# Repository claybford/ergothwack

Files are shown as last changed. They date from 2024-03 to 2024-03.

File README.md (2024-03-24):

# The ergoTHWACK: a custom wireless mechanical split keyboard

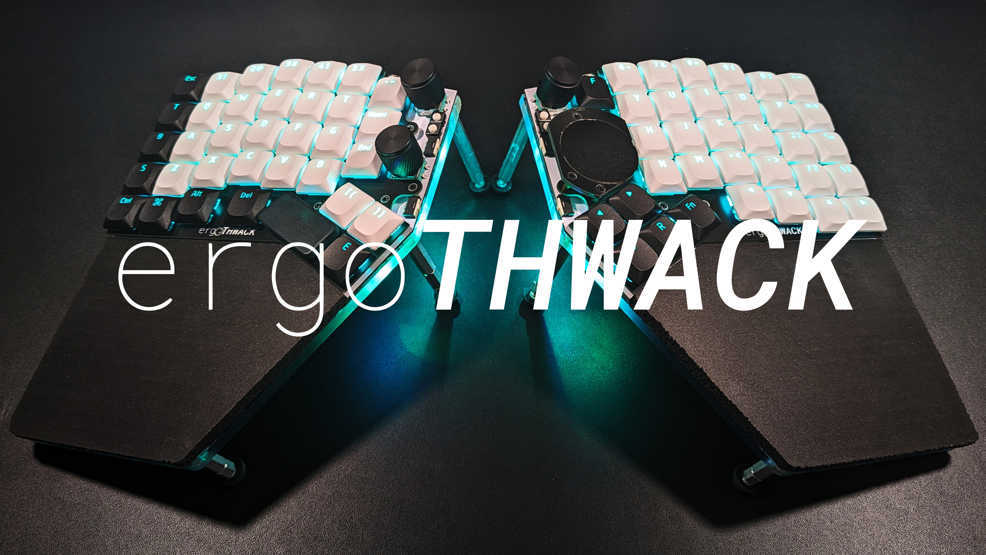
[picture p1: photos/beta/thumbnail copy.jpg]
picture alt headline photo with logo


This repository is for hardware development of the ergoTHWACK wireless mechanical split keyboard, designed by Clayton Ford.

The ergoTHWACK is a custom design, inspired by the ErgoDash by omkbd and the Corne GLP by beekeeb, that:
- requires no layer usage or memorization for general use
- has a 2U spacebar that is comfortably under the thumb for typing and gaming
- includes a Cirque Glidepoint 35mm trackpad and a rotary encoder for full mouse functionality without moving the right hand off the keyboard
- has an integrated wrist pad and tenting for ergonomics
- and uses Gateron KS-33 low-profile switches for more similarity in typing to non-mechanical keyboards.

In addition it has: 
- 2 more rotary encoders on the left
- RGB backlit keys and underglow
- tactile swiches for reset and settings control
- LED power shutoff switches
- and a 10000mAh battery on each side for plenty of wireless bluetooth backlit runtime.

For a quick overview of the design, check out the beta reveal trailer: https://www.youtube.com/watch?v=sj0JC6q0L3o

A longer write-up on the design rationale is here: https://www.claytonbford.com/portfolio/ergothwack

The ergoTHWACK uses the ZMK firmware and the nice!nano. For more information about each, please visit https://zmk.dev/ and https://nicekeyboards.com/nice-nano/ respectively.

Shield support for ZMK for the ergoTHWACK is here: https://github.com/claybford/ergothwack-shield-module

The ergoTHWACK uses a fork of ZMK to support all of its features, which its shield support repo uses and links to for building. It's directly available here: https://github.com/claybford/zmk

The ergoTHWACK keyboard is in beta, and there are several known issues with the design. Once a version is ready for others to try to build, a guide to do so will be made available!

Link to the ErgoDash by omkbd: https://github.com/omkbd/ErgoDash/tree/master

Link to the Corne GLP by beekeeb: https://github.com/beekeeb/crkbd-glp

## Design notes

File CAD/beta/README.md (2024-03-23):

Note: these CAD files are essentially the same, with the right side designed as a mirror image on the left (this is how the entire beta ergoTHWACK was designed). The only differences between these files are which bodies & components are visible on which.

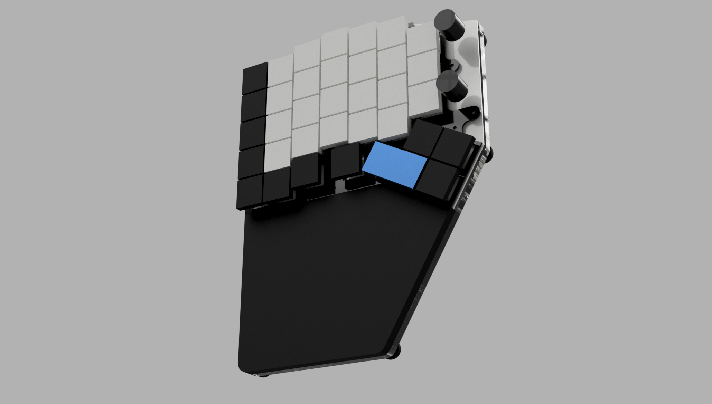
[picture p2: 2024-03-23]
renders/beta/ergothwack left.png

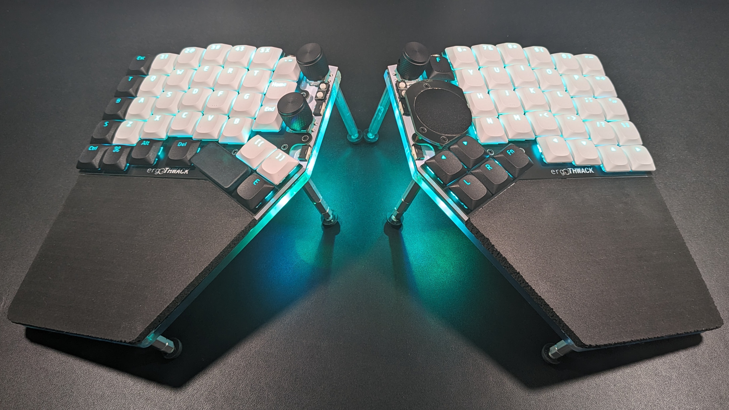
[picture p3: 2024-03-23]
photos/beta/PXL_20240321_203455422~2.jpg

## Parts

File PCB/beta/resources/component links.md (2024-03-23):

https://github.com/bstiq/nice-nano-kicad
https://github.com/madworm/Panelization.pretty
https://github.com/siderakb/key-switches.pretty
https://github.com/beekeeb/crkbd-glp

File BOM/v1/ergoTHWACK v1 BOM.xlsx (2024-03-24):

part | description | pack quantity | vendor | price | quantity | line total | subtotal | exact quantities used | notes | link | Note: exact quantities given in non-pack lines
86375K142 | Resilient Polyurethane Foam Sheet with Adhesive-Back, Ultra Soft, 12" x 12" x 1/4" |  | McMaster-Carr | 23.72 | 1 | 23.72 | $477.47 |  |  |  | retain from beta
93505A449 | Male-Female Threaded Hex Standoff Aluminum, 1/4" Hex Size, 2" Long, 6-32 Thread Size |  | McMaster-Carr | 1.34 | 2 | 2.68 | $611.49 |  |  |  | Removal from beta
93505A446 | Male-Female Threaded Hex Standoff Aluminum, 1/4" Hex Size, 1" Long, 6-32 Thread Size |  | McMaster-Carr | 0.72 | 2 | 1.44 | -$134.02 |  |  |  | targeted for change from beta
93505A442 | Male-Female Threaded Hex Standoff Aluminum, 1/4" Hex Size, 1/2" Long, 6-32 Thread Size |  | McMaster-Carr | 0.66 | 6 | 3.96 |  |  |  |  | Quantity change from beta
93505A440 | Male-Female Threaded Hex Standoff Aluminum, 1/4" Hex Size, 1/4" Long, 6-32 Thread Size |  | McMaster-Carr | 0.59 | 6 | 3.54 |  |  |  |  | v1 addition
9541K8 | Threaded-Stud Bumper SBR, 6-32 Thread, 7/16" OD, 1/4" High, Durometer 60A | 25 | McMaster-Carr | 10.84 | 1 | 10.84 |  | v1 8, beta 10 |  |  | custom component
97164A117 | Aluminum Tapered Heat-Set Inserts for Plastic M3 x 0.5 mm Thread Size, 3.81 mm Installed Length | 25 | McMaster-Carr | 8.82 | 0 | 0 |  |  | Eliminated by tapped steel baseplate |  | estimate
97164A110 | Aluminum Tapered Heat-Set Inserts for Plastic 6-32, 0.150" Installed Length | 25 | McMaster-Carr | 6.52 | 0 | 0 |  |  | Eliminated by tapped steel baseplate
94459A418 | Heat-Set Inserts for Plastic Aluminum, M2 x 0.4 mm, 4.1 mm Installed Length | 25 | McMaster-Carr | 7.75 | 0 | 0 |  |  | Eliminated by tapped steel baseplate
93935A305 | Super-Corrosion-Resistant 316 Stainless Steel Thin Hex Nut M2 x 0.4 mm Thread, 1.2 mm High | 25 | McMaster-Carr | 3.67 | 0 | 0 |  | 8 in beta | Eliminated by reversing screws
575-3154311241003000 | IC & Component Sockets Interconnect Socket 12 position |  | Mouser | 1.79 | 0 | 0 |  |  | These are too short for the nice!nanos to avoid contacting items on the underside of the pcb
575-3320000150000030 | IC & Component Sockets STANDARD I.C. PIN |  | Mouser | 0.11 | 54 | 5.94 |  |  | Updated due to elimination of adapter board
485-4960 | Adafruit Accessories NeoPixel Reverse Mount RGB LEDs - 10 Pack of SK6812-E | 10 | Mouser | 2.95 | 7 | 20.65
485-1655 | Adafruit Accessories SK6812 LEDs w/driverchip-10pack | 10 | Mouser | 4.5 | 2 | 9
621-1N4148W-F | Diodes - General Purpose, Power, Switching SURFACE MOUNT FAST SWITCHING DIODE |  | Mouser | 0.095 | 0 | 0 |  |  | Switch to dual diode packages
355-TM0350352024-002 | Capacitance Touch Sensor Modules 35mm Round SPI/I2C flat overlay |  | Mouser | 8.8 | 1 | 8.8
538-503480-1200 | FFC & FPC Connectors .5mm FPC 12P CONN RA SMT B-FLIP DUAL |  | Mouser | 1.16 | 1 | 1.16
538-15020-0117 | FFC / FPC Jumper Cables PREMO-FLEX 0.50 (AU) LGT 30 TYPEA 12CKT |  | Mouser | 3.75 | 1 | 3.75
229-CL-SA-12C4-02 | Slide Switches SPDT, ON-ON Slide, White Actuator, 500mA @ 12V DC Right Angle PC Terminals, Bulk Packaging |  | Mouser | 4.02 | 0 | 0 |  |  | Lower cost alternative identified
612-TL59NF160Q | Tactile Switches Thruhole Radial lead SPST-NO 0.05A 12V |  | Mouser | 0.29 | 6 | 1.74
179-RIC11-22S10D5STH | Encoders MECH, 20 PPR 20 DET, 5 Vdc, SW, 5 mm smth bush, D shaft, horizontal, TH |  | Mouser | 2.55 | 0 | 0 |  |  | Switch to taller encoder with XDA keycaps
B0CCPH974T | M3 Flat Head Machine Screws and Hex Nuts Kit, 380 Pcs Black Countersunk Head Phillips Screws Bolts Nuts Assortment Kit - M3 x 4mm/ 6mm/ 8mm/ 10mm/ 12mm/ 16mm/ 20mm | Many | Amazon | 8.88 | 0 | 0 |  |  | Eliminated by using M2s instead for battery plate-base plate
B07H3RTHCC | uxcell 100pcs M2 6+3mm Female Male Thread Brass Round Standoff Spacer Screw PCB Pillar | 100 | Amazon | 8.39 | 0 | 0 |  |  | Eliminated by reverse screw strategy
B0C37KSJSW | PATIKIL 3.2mm ID x 5mm OD x 4mm L Round Spacers Washers, 100 Pack Nylon Standoff Gaskets for M3 Hardware Screws Bolts for 3D Printer Electrical Outlet, White | 100 | Amazon | 8.19 | 0 | 0 |  |  | Migrating to a true 0.25mm baseplate should make these unnecessary for the battery plate, spacing becomes 3mm
B0C37FX7W5 | PATIKIL 3.2mm ID x 5mm OD x 3mm L Round Spacers Washers, 200 Pack Nylon Standoff Gaskets for M3 Hardware Screws Bolts for 3D Printer Electrical Outlet, White | 200 | Amazon | 8.59 | 0 | 0 |  |  | Eliminating pcb-top plate spacers
B0C37HT35Q | PATIKIL 3.2mm ID x 5mm OD x 2mm L Round Spacers Washers, 200 Pack Nylon Standoff Gaskets for M3 Hardware Screws Bolts for 3D Printer Electrical Outlet, White | 200 | Amazon | 8.89 | 0 | 0 |  |  | Replaced with ASTM option from McMaster-Carr
B07TXYBB7Z | mxuteuk 4pcs Black Guitar Knobs Aluminum Alloy Potentiometer Control Knob Volume Audio Electric Guitar Bass Knob Screw Type 17 x 16mm (d*h) KNOB-04-BK | 4 | Amazon | 15.88 | 1 | 15.88
B093WS6C66 | MakerFocus 3.7V LiPo Battery 10000mAh Lithium Rechargeable Battery with Integrated Protective Board, Insulation Coating and PH2.0A Plug for Raspberry Pi UPS Board and Other |  | Amazon | 19.99 | 2 | 39.98
B07BS126FK | Male and Female Pin Header (5pair) Gold Plated (ROHS) Single Row Round Pin 1 * 40 40P Straight Needle Male PCB Pin Header 2.54 mm Male Pin Header Connector Gold Used in Computer and Breadboard | 5 | Amazon | 9.99 | 0 | 0 |  |  | Change to taller Mill-Max option and elimination of adapter board
B01461DQ6S | uxcell Right Angle Single Row 40-pin 2.54mm Male Header for Breadboard (Pack of 10) | 10 | Amazon | 7.39 | 0 | 0 |  |  | Identified matching board connector for battery
B07H3V31GY | uxcell 50pcs M2 5+3mm Male Thread Brass Round Standoff Spacer Screw PCB Pillar | 50 | Amazon | 5.99 | 0 | 0 |  | 3 in beta | Change to 9mm spacer
B0B8Z23NWX | 10PCS 2P Dupont Line 2 Pins 2.54mm Pitch Female to Female Dupont Cable Connector Multicolor Jumper Wire for Breadboard 20CM | 10 | Amazon | 5.99 | 0 | 0 |  | 1 in beta | Identified matching board connector for battery
B09L4R6B1Q | Easycargo 240pcs 12 Sizes Laptop Screws Kit, Notebook Computer Replacement Screws Assortment Kit,M2 M2.5 M3, for Lenovo Toshiba Gateway Samsung HP IBM Dell Sony Acer Asus SSD Hard Disk SATA SSD M.2 | Many | Amazon | 4.99 | 0 | 0 |  |  | Fasteners from McMaster-Carr
B0BVYV67QS | Low Profile Keycaps, Shine Through Keycaps, Custom Keyboard Keycaps, Keycaps 75 Percent Full Keycaps for 60% 65% 75% 80% 100% Cherry Gateron MX Switches Mechanical Keyboard, Black Backlight |  | Amazon | 20.99 | 0 | 0 |  |  | Switch to single XDA keycap set
B0B49FLN6K | Womier Low Profile Keycaps, Shine Through Keycaps, Custom Keyboard Keycaps, Keycaps 75 Percent Full Keycaps for 60% 65% 75% 80% 100% Cherry Gateron MX Switches Mechanical Keyboard, White Backlight |  | Amazon | 20.99 | 0 | 0 |  |  | Switch to single XDA keycap set
Gateron KS-33 Low Profile 2.0 Mechanical Switch Set | Gateron KS-33 Low Profile 2.0 Mechanical Switch Set Blue / 110 Switches | 110 | gateron.co | 31 | 0 | 0 |  | 25 in beta | Can use only one switch type and eliminate | https://www.gateron.co/products/gateron-low-profile-mechanical-switch-set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
GATERON Upgrade Low Profile switch Hot-swap PCB 2.0 Socket | GATERON Upgrade Low Profile switch Hot-swap PCB 2.0 Socket | 110 | gateron.com | 11 | 1 | 11 |  |  |  | https://www.gateron.com/products/gateron-low-profile-switch-hot-swap-pcb-socket?VariantsId=10234
GATERON Low Profile Plate Mounted Stabilizer | GATERON Low Profile Plate Mounted Stabilizer |  | gateron.com | 1.2 | 1 | 1.2 |  |  |  | https://www.gateron.com/products/gateron-low-profile-plate-mounted-stabilizer?VariantsId=10477
GATERON KS-33 Low Profile 2.0 Banana Switch Set | GATERON KS-33 Low Profile 2.0 Banana Switch Set | 35 | gateron.com | 9.8 | 2 | 19.6 |  | 44 in beta |  | https://www.gateron.com/products/gateron-ks-33-low-profile-20-banana-switch?VariantsId=10734
CUSTOM | ergothwack-upper components extra panel space pcb panel | 5 | JLCPCB | 66.75 | 0 | 0 |  |  | Merchandise Total:$36.93 Shipping Charge:$26.04 Sales Tax:$3.78 Order Total:$66.75
CUSTOM | ergothwack pcb panel | 5 | JLCPCB | 47.82 | 0 | 0 |  |  | Merchandise Total:$29.13 Shipping Charge:$15.98 Sales Tax:$2.71 Order Total:$47.82
CUSTOM | battery plate 5052 H32 Aluminum (.063") with deburring | 2 | sendcutsend.com | 6.42 | 0 | 0
CUSTOM | base plate Polycarbonate-Clear (.220") | 2 | sendcutsend.com | 35.86 | 0 | 0
nice!nano v2.0 | nice!nano v2.0 |  | typeractive.xyz | 25 | 2 | 50
90176A128 | Nylon Unthreaded Spacers 1/4" OD, 1/8" Long, Black | 25 | McMaster-Carr | 3.88 | 1 | 3.88
92985A817 | Splined Press-Fit Threaded Standoffs with Open End Miniature, 3.2 mm OD, 2 mm Long | 25 | McMaster-Carr | 4.65 | 1 | 4.65
91292A835 | 18-8 Stainless Steel Socket Head Screw M2 x 0.4 mm Thread, 14 mm Long | 50 | McMaster-Carr | 3.5 | 1 | 3.5
92703A445 | 18-8 Stainless Steel Torx Flat Head Screws M2 x 0.40 mm Thread Size, 10 mm Long | 100 | McMaster-Carr | 3.27 | 1 | 3.27
93395A136 | 316 Stainless Steel Hex Drive Flat Head Screw 90 Degree Countersink, M2 x 0.40mm Thread, 4mm Long | 25 | McMaster-Carr | 6.34 | 1 | 6.34
93657A503 | Nylon Unthreaded Spacer 4.5 mm OD, Off-White, 9 mm Long, for M3 Screw Size |  | McMaster-Carr | 1.96 | 3 | 5.88 |  |  | Replaces pcb-base and base-battery plate spacers. Pcb-top plate spacers eliminated. Check if 25 is sufficient, and that 0.25 fits where necessary
B01DUC1O68 | 20 Sets Mini Micro Jst 2.0 Ph 2-Pin Connector Plug Male with 150mm Cable & Female | 20 | Amazon | 8.59 | 1 | 8.59
B09J1G8RGF | LTC LavaCaps PBT Double Shot 117-Key Pudding Keycaps Set, Translucent XDA Profile for ISO & ANSI Layout 61/68/84/87/104 Keys Mechanical Keyboard, with Keycap Puller - (Only Keycaps), White |  | Amazon | 19.99 | 1 | 19.99
575-3104711241001000 | IC & Component Sockets STANDRD SOLDER TAIL SIP SOCKET 12 position |  | Mouser | 1.3 | 4 | 5.2
575-3104710341001000 | IC & Component Sockets STANDRD SOLDER TAIL SIP SOCKET 3 position |  | Mouser | 0.6 | 2 | 1.2
667-EXB-34V102JV | Resistor Networks & Arrays Resistor ArrayChip 2 elements |  | Mouser | 0.2 | 1 | 0.2
771-BAV70235 | Diodes - General Purpose, Power, Switching BAV70/SOT23/TO-236AB |  | Mouser | 0.082 | 40 | 3.28
179-RIC11-22S15D7-TH | Encoders MECH, 20 PPR 20 DET, 5 Vdc, SW, 7 mm smth bush, D shaft, horizontal, TH |  | Mouser | 2.55 | 3 | 7.65
123-09.10290.01 | Slide Switches 1K2 BLK ACT GOLD RIGHT ANGL MNT |  | Mouser | 2.18 | 4 | 8.72
CUSTOM | ergothwack pcb panel | 5 | JLCPCB | 47.82 | 1 | 47.82
CUSTOM | battery plate mild steel 0.048" | 2 | sendcutsend.com | 6.42 | 1 | 6.42
CUSTOM | glow plate acrylic 0.118" | 2 | sendcutsend.com | 5 | 1 | 5
CUSTOM | base plate mild steel 0.25" with tapped holes and powder coating | 2 | sendcutsend.com | 40 | 1 | 40
CUSTOM | top plate mild steel 0.048" | 2 | sendcutsend.com | 30 | 1 | 30
CUSTOM | cirque plate a mild steel 0.048" |  | sendcutsend.com | 3 | 1 | 3
CUSTOM | cirque plate b mild steel 0.048" |  | sendcutsend.com | 3 | 1 | 3
CUSTOM | nice holders acrylic? | 2 | sendcutsend.com | 6 | 1 | 6
CUSTOM | vinyl label | 2 | stickermule.com | 19 | 1 | 19
 |  |  |  |  |  | 0
 |  |  |  |  |  | 0
 |  |  |  |  |  | 0
 |  |  |  |  |  | 0
 |  |  |  |  |  | 0
 |  |  |  |  |  | 0
 |  |  |  |  |  | 0
 |  |  |  |  |  | 0
 |  |  |  |  |  | 0
 |  |  |  |  |  | 0
 |  |  |  |  |  | 0
 |  |  |  |  |  | 0
 |  |  |  |  |  | 0
 |  |  |  |  |  | 0
 |  |  |  |  |  | 0
 |  |  |  |  |  | 0
 |  |  |  |  |  | 0
 |  |  |  |  |  | 0
 |  |  |  |  |  | 0
 |  |  |  |  |  | 0
 |  |  |  |  |  | 0
 |  |  |  |  |  | 0
 |  |  |  |  |  | 0
 |  |  |  |  |  | 0
 |  |  |  |  |  | 0
 |  |  |  |  |  | 0
 |  |  |  |  |  | 0
 |  |  |  |  |  | 0
 |  |  |  |  |  | 0
 |  |  |  |  |  | 0
 |  |  |  |  |  | 0
 |  |  |  |  |  | 0

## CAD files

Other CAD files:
CAD/beta/ergothwack-left.f3d
CAD/beta/ergothwack-right (requires mirroring).f3d

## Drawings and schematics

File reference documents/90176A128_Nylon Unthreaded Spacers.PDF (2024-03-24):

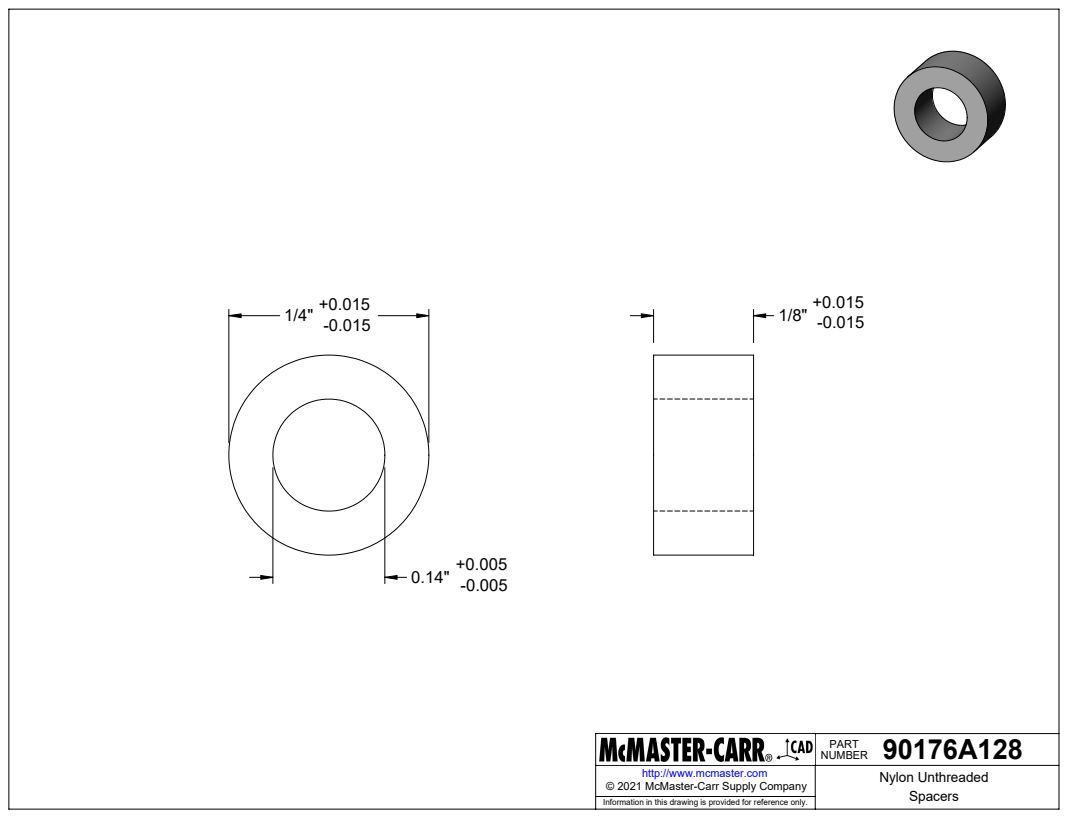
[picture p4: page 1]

90176A128 PART NUMBER

http://www.mcmaster.com | Nylon Unthreaded Spacers © 2021 McMaster-Carr Supply Company

Information in this drawing is provided for reference only.

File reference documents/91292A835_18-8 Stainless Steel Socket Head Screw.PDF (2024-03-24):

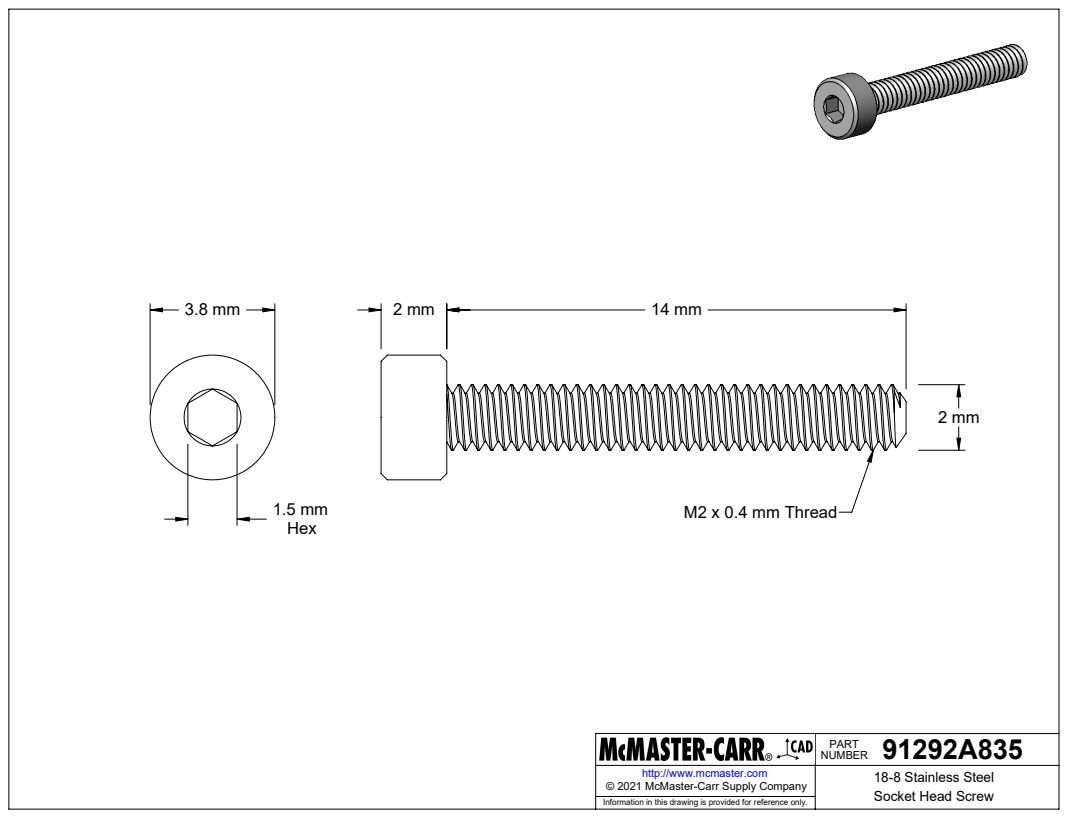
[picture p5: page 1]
M2 x 0.4 mm Thread

91292A835 PART NUMBER

http://www.mcmaster.com | 18-8 Stainless Steel Socket Head Screw © 2021 McMaster-Carr Supply Company

Information in this drawing is provided for reference only.

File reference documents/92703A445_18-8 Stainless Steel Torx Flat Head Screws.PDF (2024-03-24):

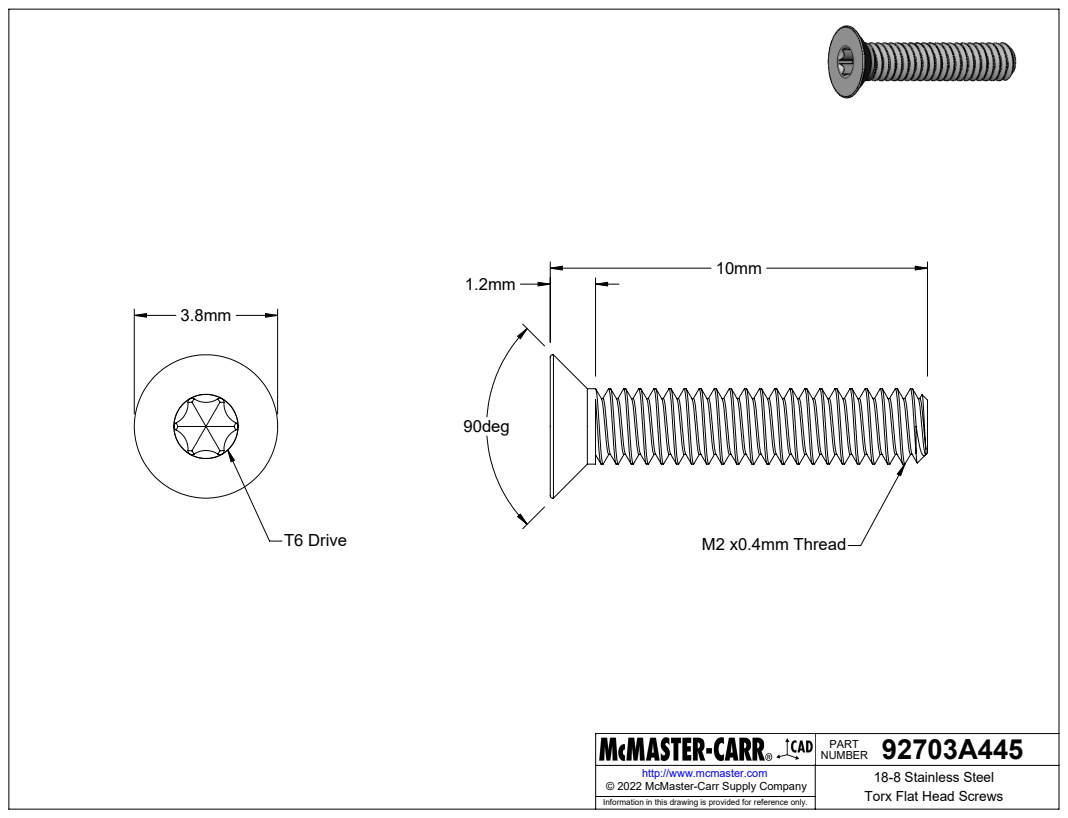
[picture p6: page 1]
T6 Drive; M2 x0.4mm Thread

92703A445 PART NUMBER

http://www.mcmaster.com | 18-8 Stainless Steel Torx Flat Head Screws © 2022 McMaster-Carr Supply Company

Information in this drawing is provided for reference only.

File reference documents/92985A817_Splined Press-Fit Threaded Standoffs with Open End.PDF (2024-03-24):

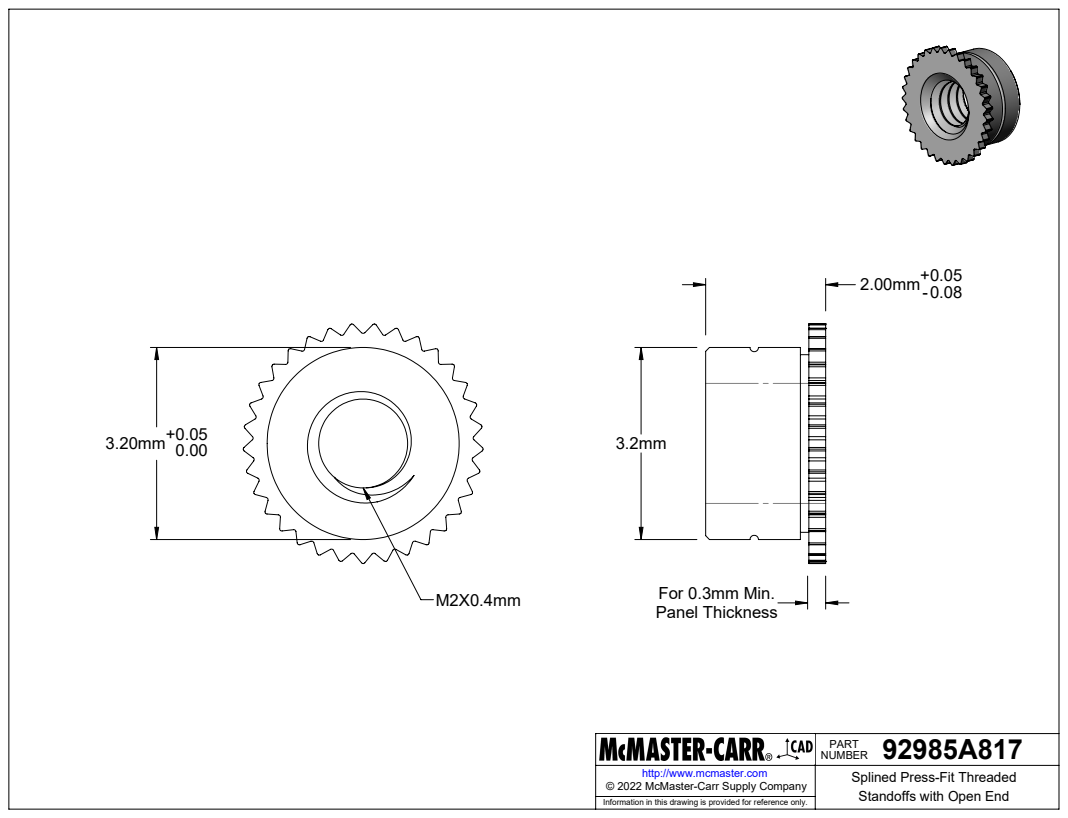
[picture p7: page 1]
For 0.3mm Min. Panel Thickness

92985A817 PART NUMBER

http://www.mcmaster.com | Splined Press-Fit Threaded Standoffs with Open End © 2022 McMaster-Carr Supply Company

Information in this drawing is provided for reference only.

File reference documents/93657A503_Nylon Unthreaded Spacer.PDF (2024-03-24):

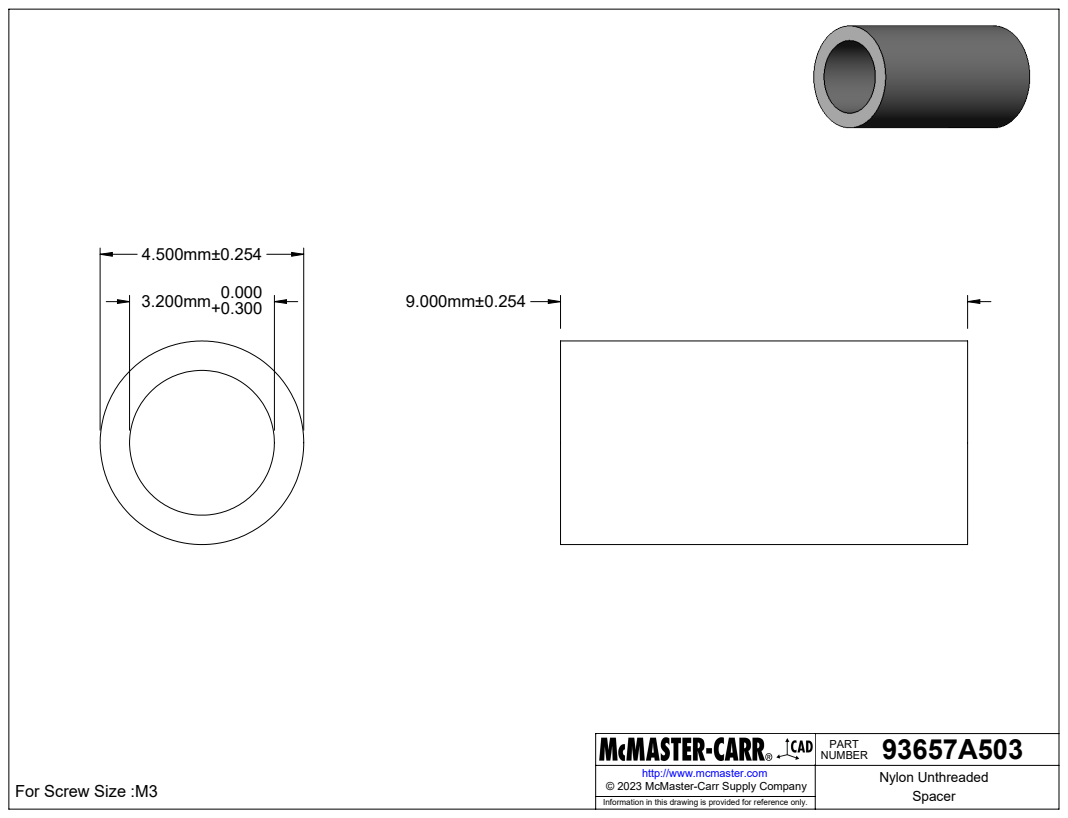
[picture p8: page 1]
For Screw Size :M3; Spacer © 2023 McMaster-Carr Supply Company

93657A503 PART NUMBER

http://www.mcmaster.com | Nylon Unthreaded

Information in this drawing is provided for reference only.

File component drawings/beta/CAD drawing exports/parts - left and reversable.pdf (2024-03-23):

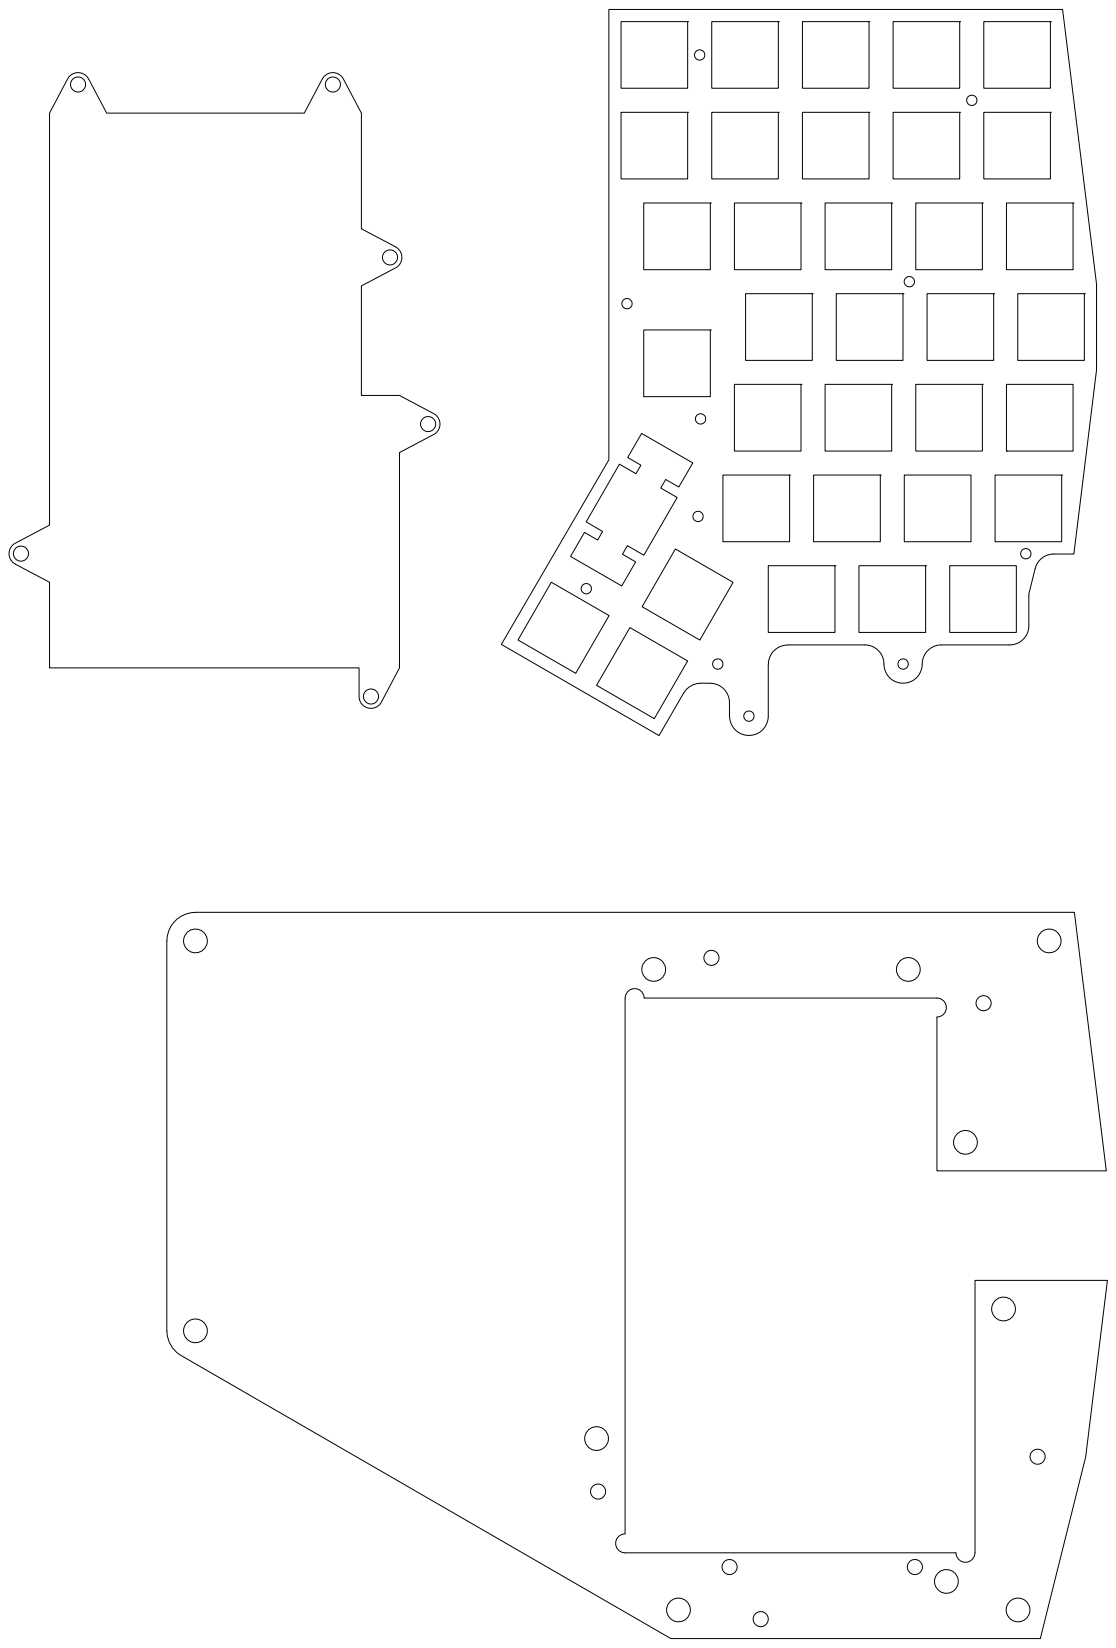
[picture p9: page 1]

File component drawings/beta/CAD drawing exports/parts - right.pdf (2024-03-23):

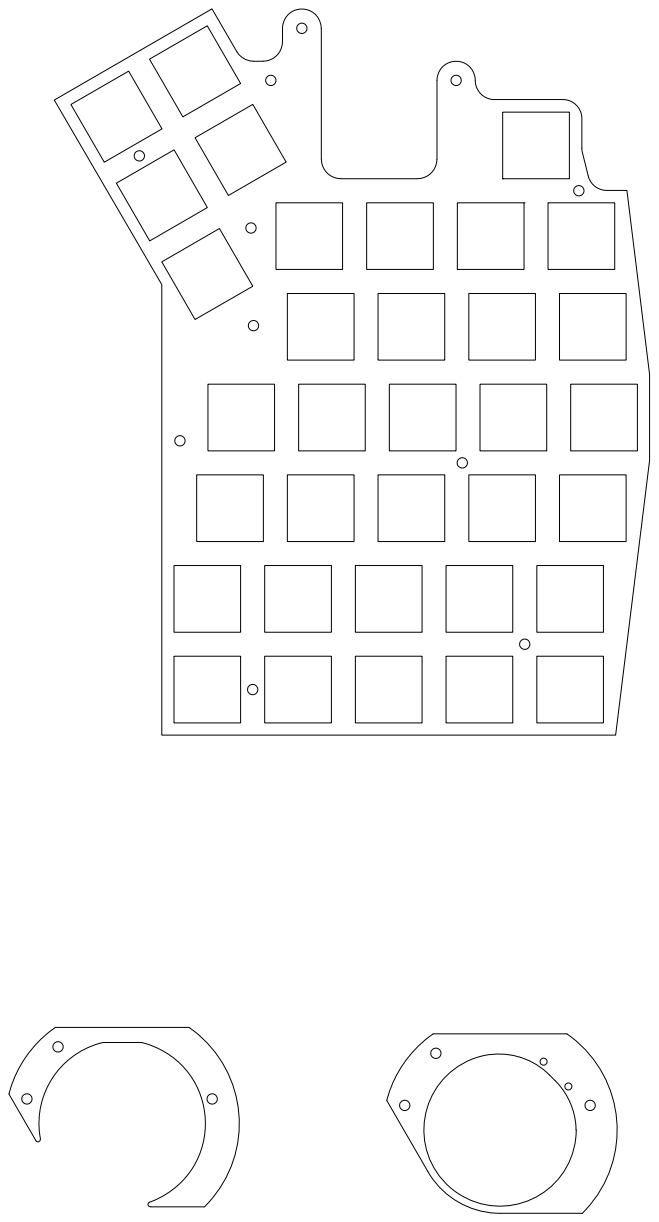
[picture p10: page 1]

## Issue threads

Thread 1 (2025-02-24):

General question

marcelotrevisani, 2025-02-24:
Hello,

Thanks for this project! I am really interested in building this, but I am a bit lost with all the files and so.
Are you still maintaining the project please?
and could you share some sort of tutorial if you don't mind? thanks! :)

claybford, 2025-02-26:
Hi @marcelotrevisani ! Sorry I haven't put much more into progressing this design, been busy and decided to do a new design next instead of directly iterating this one. Glad to answer questions! There should be a parts list for the beta, then kicad for the pcbs and plates. then vector graphics for the other 2.5d parts to be made/ordered e.g. from sendcutsend. note that there are a number of known design issues - eg plate can't be installed the correct way because the spacebar stab needs clearance in the main pcb, there's a missing ground connection on an LED, and the baseplate nice!nano/daughterboard clearance is wrong on the right side. also the CS line isnt connected to the trackpad connector, and needs to be for it to work. Probably im forgetting some things but i think those were the major ones, so this will require a bit of progression still to replicate easily.

marcelotrevisani, 2025-02-27:
Hi @claybford ,
Thanks for your answer! I think it might be wise for me to wait for your next project then :)

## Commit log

2024-03-23 Add nice!nanos to beta BOM
    [ergoTHWACK beta BOM.xlsx]
2024-03-24 Add v1 BOM draft and data sheets
    [ergoTHWACK v1 BOM.xlsx]
2024-03-24 Fix quantity of beta power switches to 0
    [ergoTHWACK v1 BOM.xlsx]
